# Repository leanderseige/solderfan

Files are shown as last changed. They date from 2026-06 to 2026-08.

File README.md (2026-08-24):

# SolderFan

SolderFan is a modular fume extractor project. It features

- multiple serial 120mm fans (PC case fan standard)
- 100mmm hose adapters
- filter modules for activated carbon filters and for particle filters
- microcontroller based speed adjustment (pwm)
- remote control via bluetooth (from your smartphone or computer)
- tachometer support

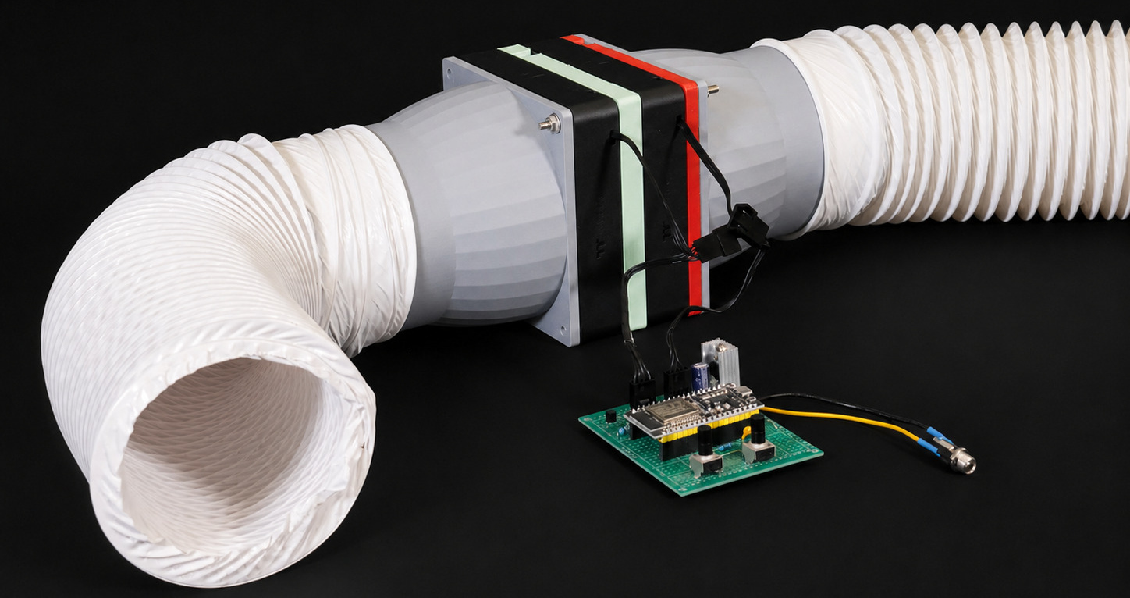
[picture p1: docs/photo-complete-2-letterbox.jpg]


**Disclaimer: This fume extraction system was not professionally designed, engineered, or evaluated. It is an amateur attempt to come up with a practical solution.**

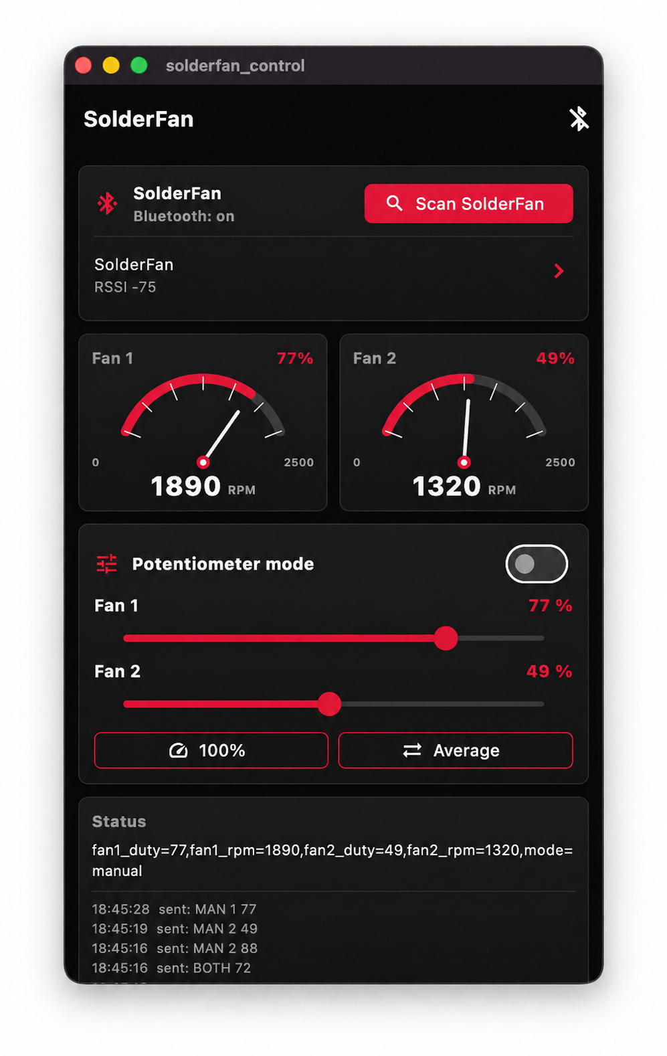
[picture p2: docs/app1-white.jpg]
  

The two-channel ESP32 controller drives two fans with 25 kHz PWM, reads their
tachometer signals, supports an automatic mode through two potentiometers, and
can be controlled over BLE from a Flutter app.

This repository includes STL models for mechanically connecting 120 mm
fans to DN100 hoses.

### Project Layout

```text
.
|-- app/       Flutter app for BLE control
|-- docs/      Schematic and photos
|-- esp32/     PlatformIO project for the ESP32 firmware
`-- stl/       3D models for filter holders, spacers and DN100 hose adapters
```

### Hardware

The firmware is designed for an ESP32 DevKit and two 4-pin PC fans. The fan PWM
outputs are driven through BC547 open-collector stages. Because of that, the PWM
signal is inverted in firmware.

| Function | ESP32 GPIO | Notes |
| --- | ---: | --- |
| Fan 1 tachometer | GPIO19 | Input with internal pull-up |
| Fan 2 tachometer | GPIO18 | Input with internal pull-up |
| Fan 1 PWM | GPIO23 | Through BC547 open-collector stage |
| Fan 2 PWM | GPIO22 | Through BC547 open-collector stage |
| Fan 1 potentiometer | GPIO32 | ADC1_CH4 |
| Fan 2 potentiometer | GPIO33 | ADC1_CH5 |
| 3V3 | - | Potentiometers and tachometer pull-ups |
| GND | - | Common ground for ESP32, fan supply, and signals |

Important: 4-pin PC fans usually require a 12 V supply. The ESP32 3V3 rail is
only intended for signal levels, potentiometers, and pull-ups. The fan supply
ground must be connected to ESP32 GND. The firmware enables the ESP32 internal
pull-ups for the tachometer inputs; if high-RPM readings are still unstable, use
stronger external pull-ups such as 4.7 kOhm to 10 kOhm to 3V3.

### Schematic

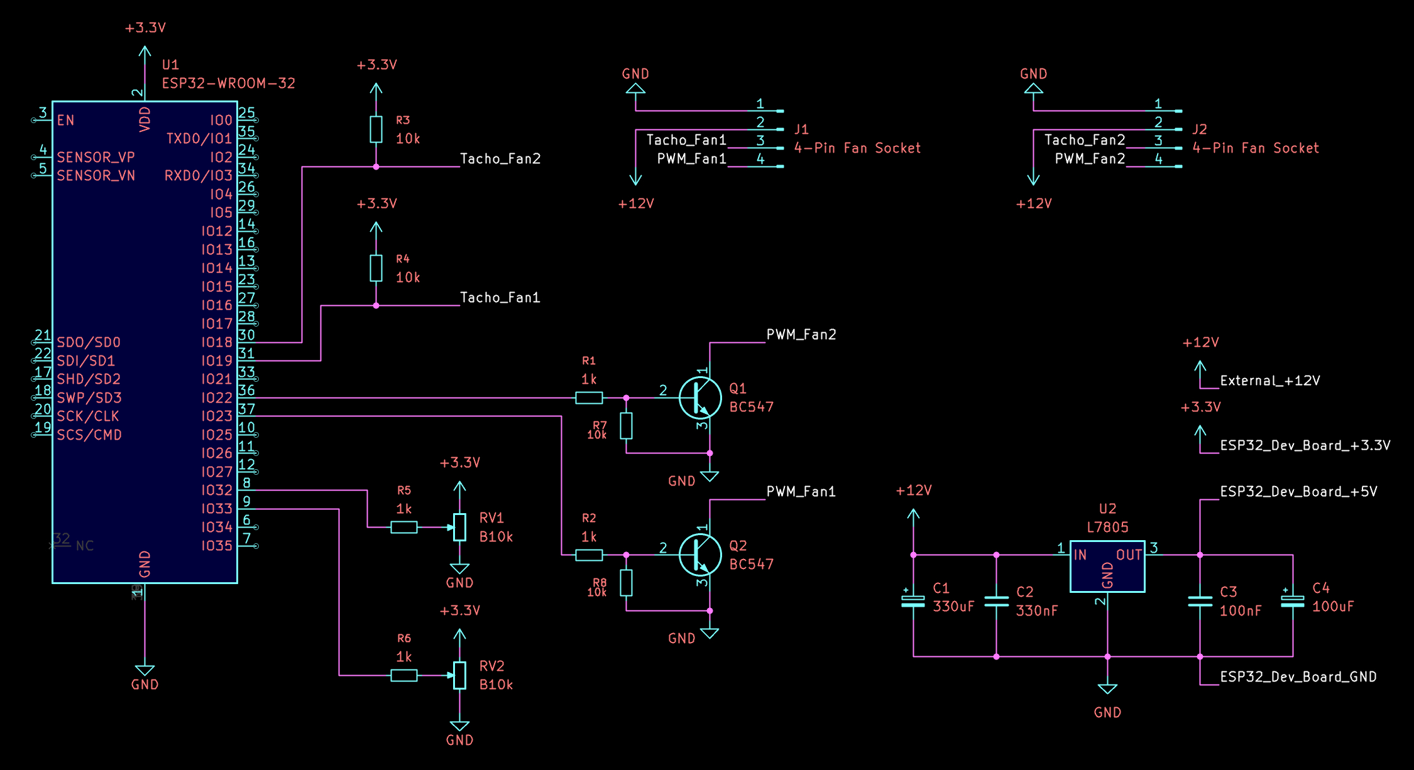
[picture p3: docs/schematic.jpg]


### Firmware

The firmware lives in `esp32/` and is built with PlatformIO.

```bash
cd esp32
pio run
```

Upload:

```bash
cd esp32
pio run -t upload
```

On macOS, you can also use the included script. It uses the first detected port
matching `/dev/cu.usbserial-*`.

```bash
cd esp32
./upload.sh
```

Serial monitor:

```bash
cd esp32
pio device monitor -b 115200
```

### Firmware Behavior

- PWM frequency: 25 kHz
- PWM resolution: 8 bit
- Minimum automatic-mode duty: 20 %
- Tachometer calculation: ESP32 PCNT hardware counter, 2 pulses per revolution
- Automatic mode: Fan 1 follows the potentiometer on GPIO32; Fan 2 follows the
  potentiometer on GPIO33
- Startup behavior: both fans briefly run at 100 %, then fall back to 40 %
- Status output: once per second over Serial and BLE Notify

### BLE Protocol

The ESP32 advertises as:

```text
SolderFan
```

Service UUID:

```text
6e400001-b5a3-f393-e0a9-e50e24dcca9e
```

Write characteristic for commands:

```text
6e400002-b5a3-f393-e0a9-e50e24dcca9e
```

Read/Notify characteristic for status:

```text
6e400003-b5a3-f393-e0a9-e50e24dcca9e
```

Supported text commands:

| Command | Effect |
| --- | --- |
| `AUTO` | Enable automatic mode; the potentiometers control the fans |
| `STATUS` | Send the current status through Notify |
| `BOTH 80` | Manual mode, set both fans to 80 % |
| `MAN 1 70` | Manual mode, set Fan 1 to 70 % |
| `MAN 2 55` | Manual mode, set Fan 2 to 55 % |

Status format:

```text
fan1_duty=40,fan1_rpm=1230,fan2_duty=42,fan2_rpm=1260,mode=auto
```

For quick BLE testing, use a tool such as nRF Connect: scan for the `SolderFan`
device, connect to the service, and write commands as text to the write
characteristic.

## Flutter App



So far I used the app on my laptop only. However it should be possible to run it on phones as well.

The app lives in `app/` and uses `flutter_blue_plus` and `permission_handler`.

```bash
cd app
flutter pub get
flutter run
```

The app scans for the SolderFan BLE service, connects to the ESP32, subscribes
to status notifications, and provides:

- Automatic-mode switch
- Manual sliders for Fan 1 and Fan 2
- Buttons to set both fans to 100 % or to their shared average
- Status display and a small connection/command log

### Android

The required BLE permissions are documented in
`app/android/AndroidManifest-permissions-snippet.xml`. Add them to
`app/android/app/src/main/AndroidManifest.xml` directly below the `<manifest>`
element.

### iOS

The required Bluetooth usage strings are documented in
`app/ios/Info.plist-snippet.xml`. Add them to `ios/Runner/Info.plist` inside the
main `<dict>`. BLE is only practical on real iOS hardware, not in the simulator.

### macOS

For macOS, Bluetooth permissions must be enabled in the Runner entitlements. The
file `app/macos/Runner/DebugProfile.entitlements` is the relevant starting point
in this project.

## STL Models

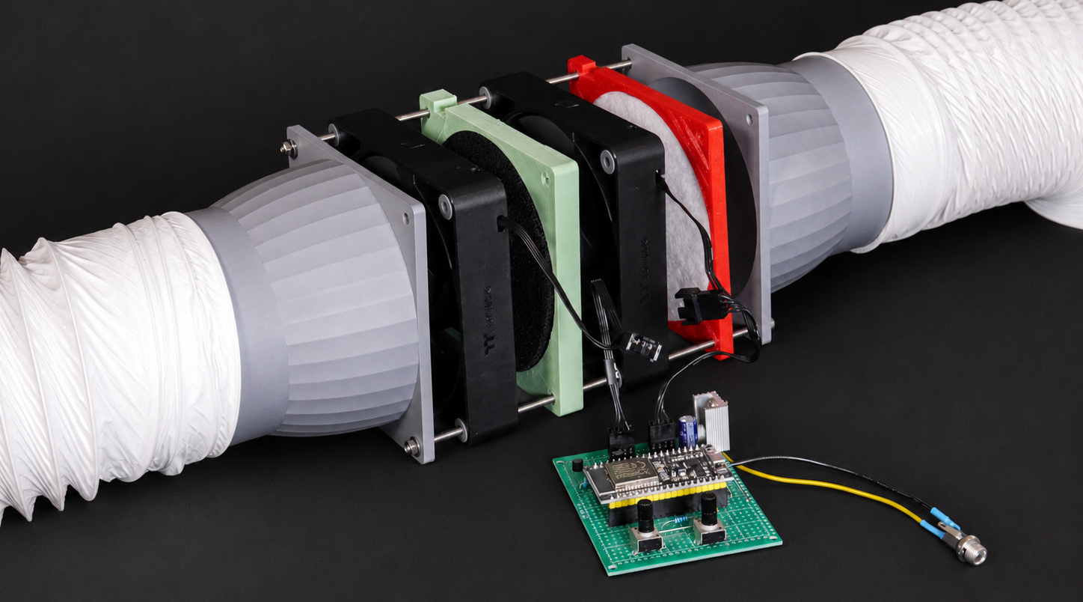
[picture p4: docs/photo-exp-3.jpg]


(Exploded View)

The `stl/` folder contains 3d-models for filter holders, DN100 adapters and spacers.

The models are intended as adapter or spacer parts for combining a 120 mm fan
with DN100 ducting. 

Practical printing notes:

- Check the model dimensions in the slicer before printing.
- Compare the fan mounting hole pattern and DN100 connection against the real
  parts.
- For ABS, ASA, or PETG, use enough wall thickness and consider the temperature
  of the operating environment.

## Filters

The project currently offers two types of filter holders: one for thin particle filter fabric (red) and one for activated carbon filters (green).

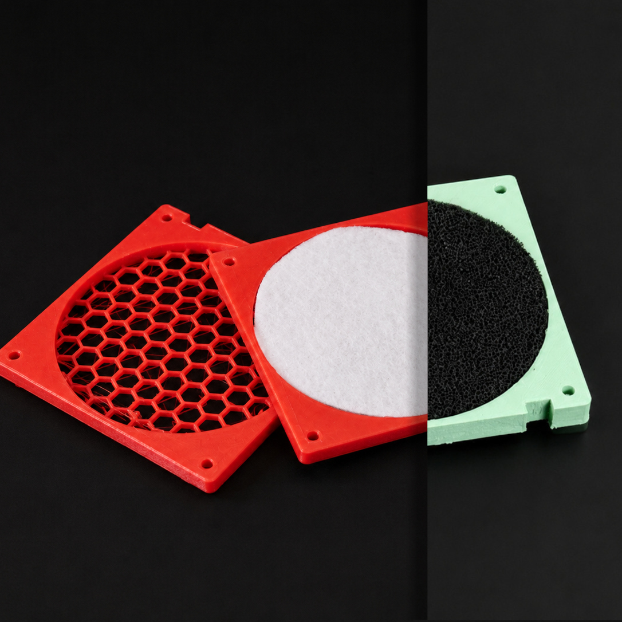
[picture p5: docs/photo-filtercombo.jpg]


## Development Notes

- Generated PlatformIO and Flutter artifacts are ignored through the root
  `.gitignore`.
- The root README is the central project documentation; there is intentionally
  no separate README in the app folder.
- Firmware and app share the BLE protocol. If UUIDs or commands change,
  `esp32/src/main.cpp` and `app/lib/main.dart` must be updated together.

## External Links

- Particle Filter: https://link.amazon/B0b2hkyDI
- Activated Carbon Filter: https://link.amazon/B08j2p6j4
- 120mm Fans (a pair, two): https://link.amazon/B0bdGr0G0
- ESP32 Development Board: https://link.amazon/B0gnhxHe7
- Threaded Rods (M4, 100mm): https://www.amazon.de/dp/B0F1T4DMW3/?tag=seigedigita03-21
- Threaded Rods (M4, 200mm): https://link.amazon/B0fxoyF9D
- 100mm Hose: https://www.ebay.de/itm/384384792852

## Next Ideas

- Presets (Stop / Min / Max / User) incl. Quick Buttons
- Support for local displays / touchscreens
- Support for >2 fans
- Proximity sensor (automatically speed up/down)
- IR sensor (automatically speed up/down)

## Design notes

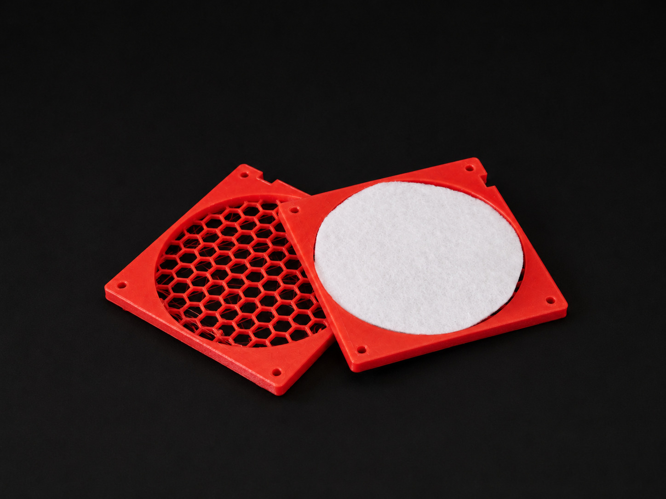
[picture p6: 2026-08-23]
docs/photo-smallfilter-1.jpg

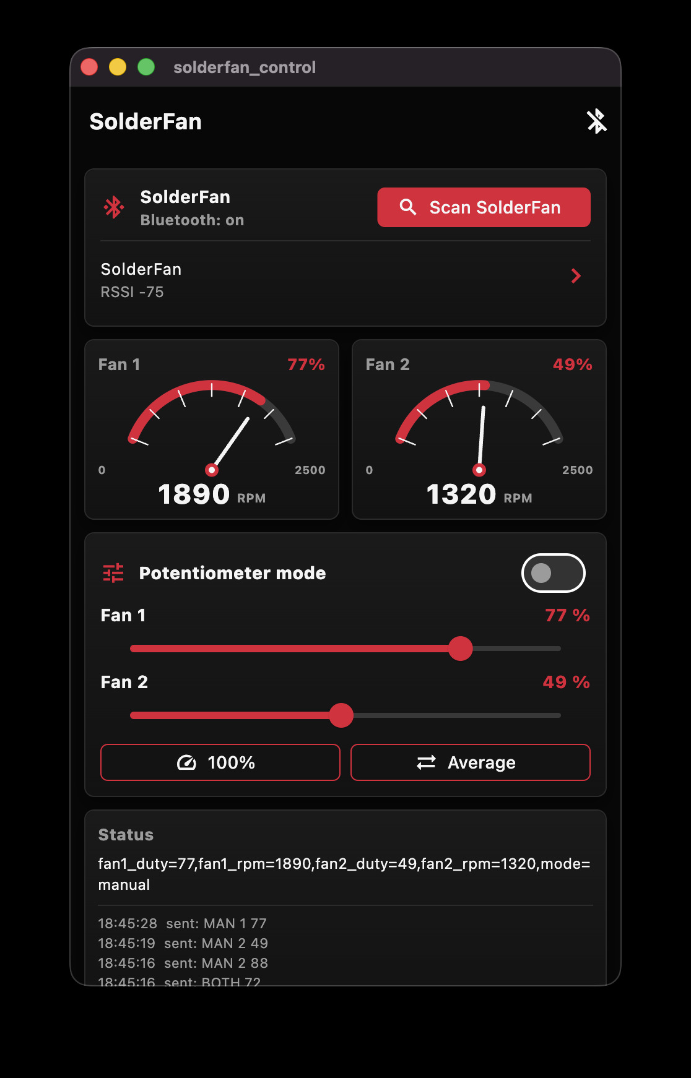
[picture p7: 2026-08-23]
docs/app1.jpg

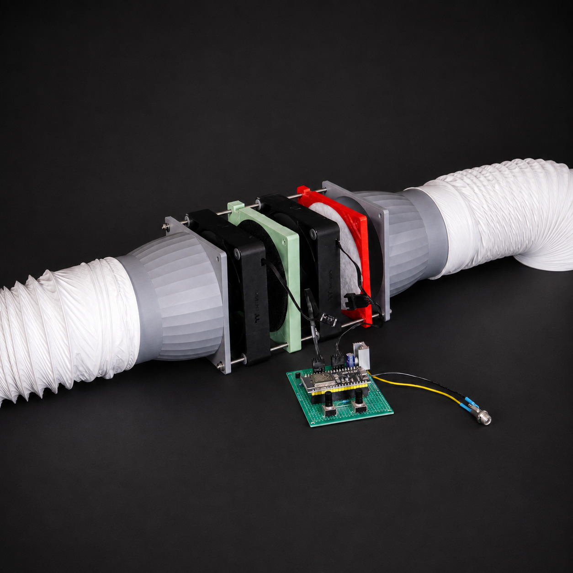
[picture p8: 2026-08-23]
docs/photo-exp-2.jpg

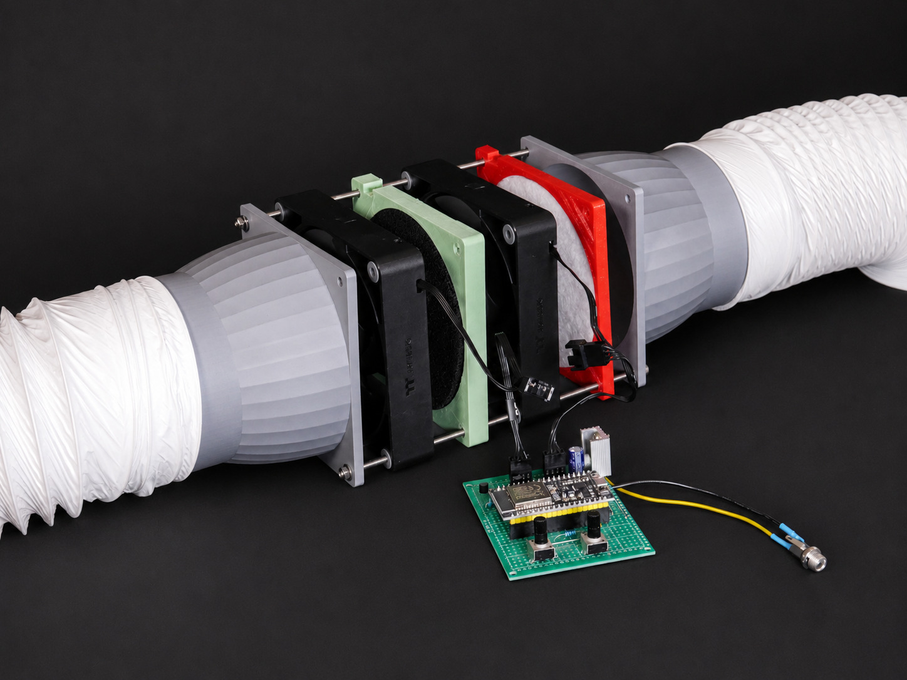
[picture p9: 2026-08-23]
docs/photo-exp-1.jpg

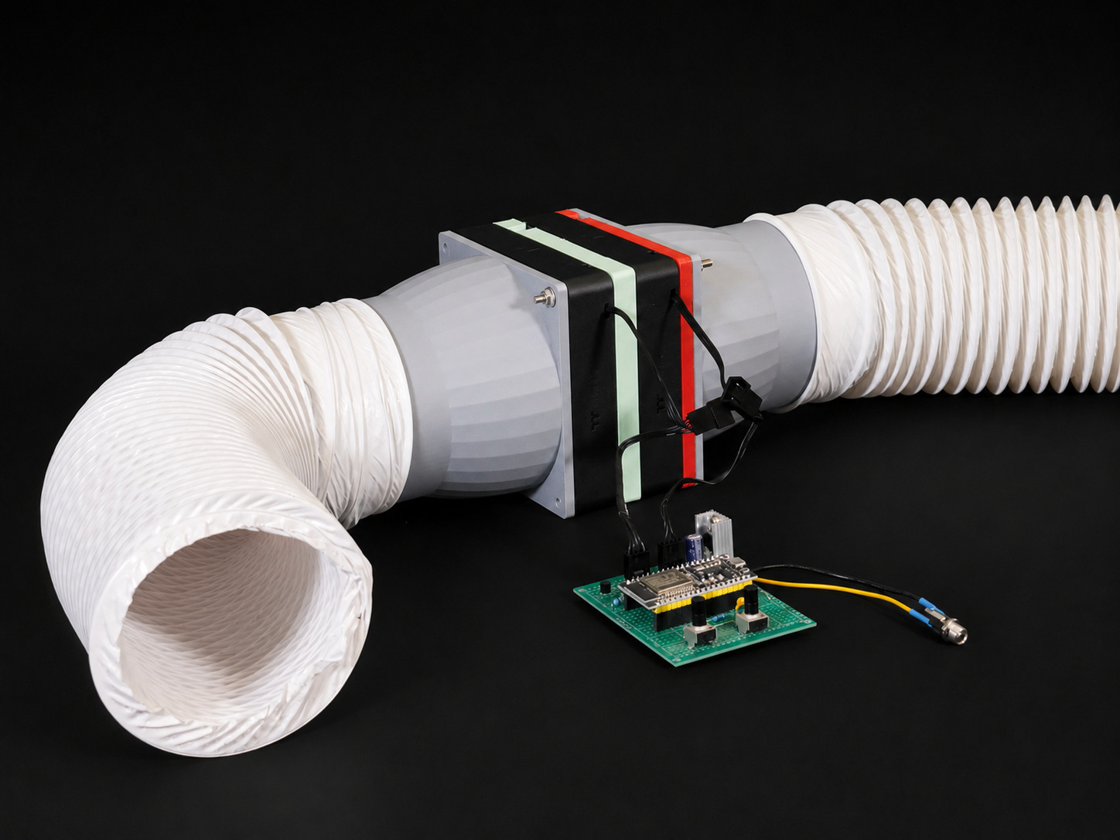
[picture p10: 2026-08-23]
docs/photo-complete-1.jpg

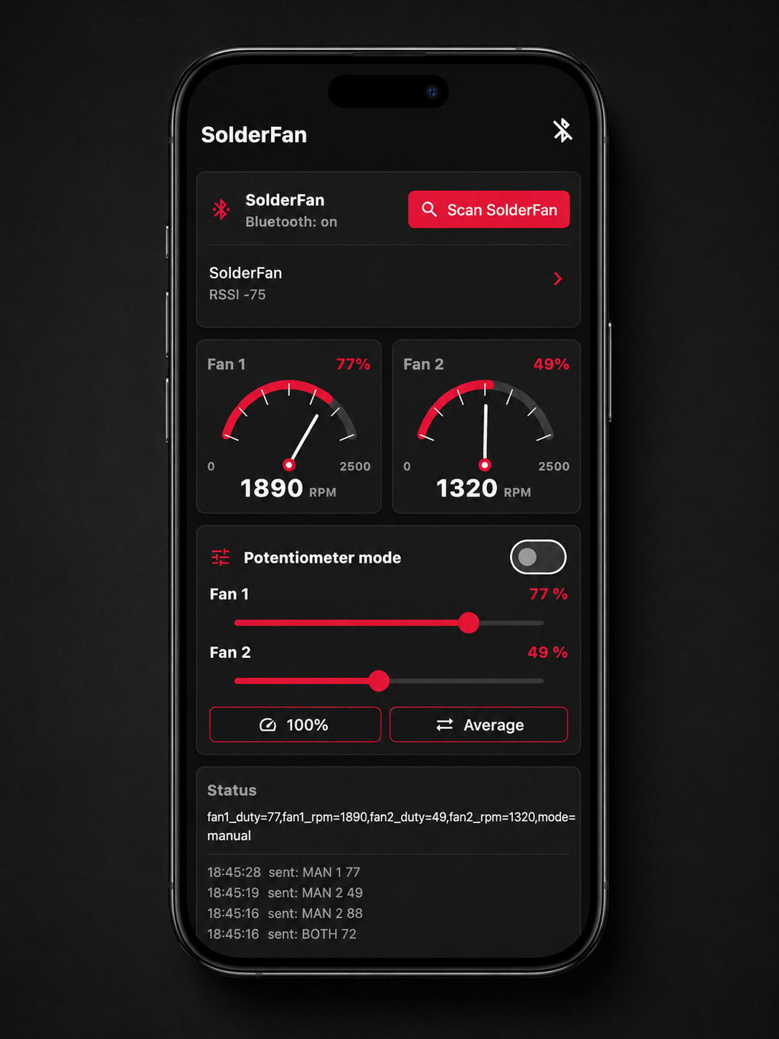
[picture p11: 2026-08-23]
docs/AI-smartphone.jpg

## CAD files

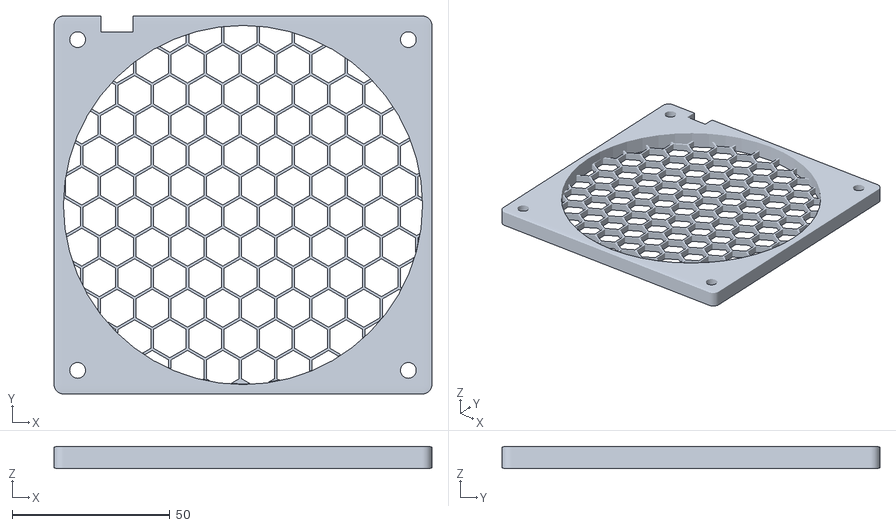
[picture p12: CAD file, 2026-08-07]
stl/filter_4mm.stl
120.0 x 120.0 x 7.00

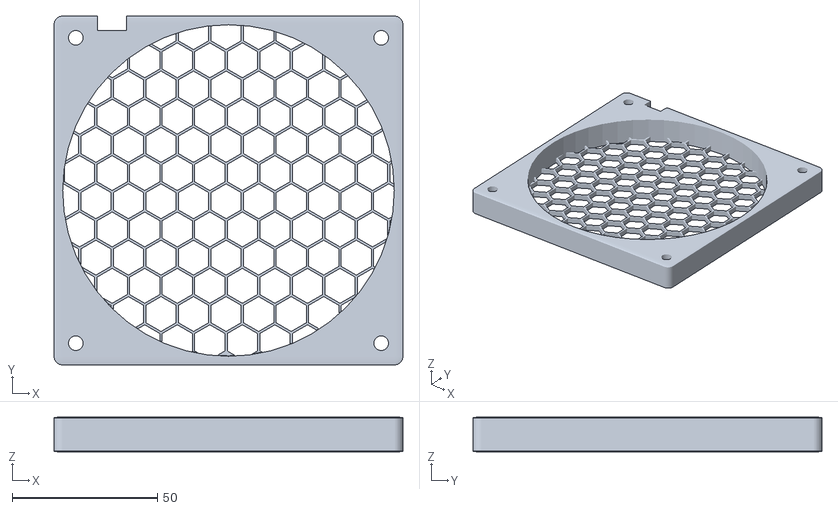
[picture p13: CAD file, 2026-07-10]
stl/filter_10mm.stl
120.0 x 120.0 x 12.0

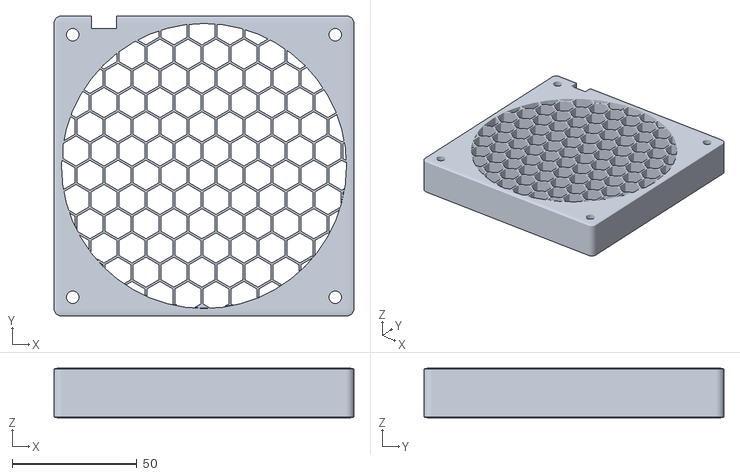
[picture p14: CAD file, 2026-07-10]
stl/hexagons.stl
120.0 x 120.0 x 20.0

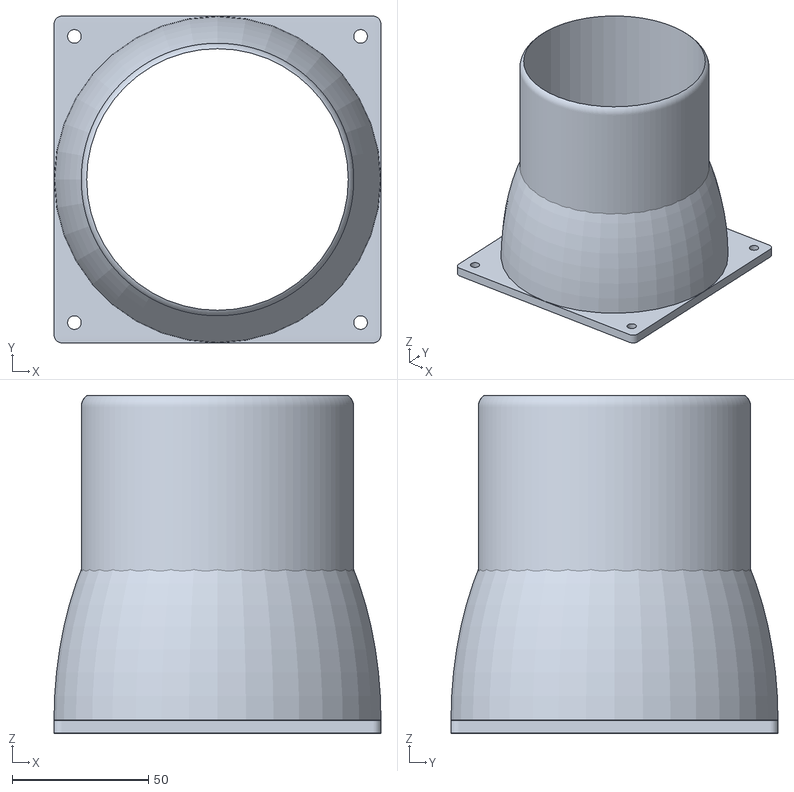
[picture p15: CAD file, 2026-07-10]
stl/DN100_adapter.stl
120.0 x 120.0 x 124.1

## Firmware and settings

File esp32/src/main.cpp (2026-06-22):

#include <Arduino.h>
#include <driver/pcnt.h>
#include <NimBLEDevice.h>

// -------------------- Pins --------------------

constexpr int FAN1_PWM_PIN  = 23;
constexpr int FAN2_PWM_PIN  = 22;

constexpr int FAN1_TACH_PIN = 19;
constexpr int FAN2_TACH_PIN = 18;

constexpr int FAN1_POT_PIN  = 32; // ADC1_CH4
constexpr int FAN2_POT_PIN  = 33; // ADC1_CH5

// -------------------- Fan/PWM settings --------------------

// 4-Pin-PC-Lüfter: typischer PWM-Wert ca. 25 kHz
constexpr uint32_t PWM_FREQ_HZ = 25000;
constexpr uint8_t  PWM_RES_BITS = 8;   // 0..255

// Arduino-ESP32 2.x nutzt LEDC-Kanäle, 3.x arbeitet direkt mit Pins.
constexpr uint8_t FAN1_PWM_CHANNEL = 0;
constexpr uint8_t FAN2_PWM_CHANNEL = 1;

constexpr uint8_t DUTY_MIN_PERCENT = 20;   // unterhalb laufen manche Lüfter unsicher
constexpr uint8_t DUTY_MAX_PERCENT = 100;

// Achtung: mit BJT/Open-Collector ist das Signal invertiert.
// ESP32 HIGH -> BJT leitet -> PWM-Pin des Lüfters LOW.
// Daher invertieren wir die Duty-Ausgabe.
constexpr bool PWM_INVERTED_BY_BJT = true;

// Tacho: PC-Lüfter meist 2 Pulse pro Umdrehung
constexpr uint8_t TACH_PULSES_PER_REV = 2;
constexpr pcnt_unit_t FAN1_TACH_PCNT_UNIT = PCNT_UNIT_0;
constexpr pcnt_unit_t FAN2_TACH_PCNT_UNIT = PCNT_UNIT_1;
constexpr uint16_t TACH_PCNT_FILTER_CYCLES = 1000; // 12.5 us bei 80 MHz APB

// -------------------- State --------------------

uint16_t fan1Rpm = 0;
uint16_t fan2Rpm = 0;

uint8_t fan1DutyPercent = 0;
uint8_t fan2DutyPercent = 0;

bool autoMode = true;

// Für getrennte Regelung kannst du später z.B. fan2 etwas schneller laufen lassen:
int8_t fan1OffsetPercent = 0;
int8_t fan2OffsetPercent = 0;

// BLE
constexpr const char* BLE_DEVICE_NAME = "SolderFan";
NimBLECharacteristic* statusCharacteristic = nullptr;

// -------------------- Helpers --------------------

uint8_t clampPercent(int value) {
  if (value < 0) return 0;
  if (value > 100) return 100;
  return static_cast<uint8_t>(value);
}

uint8_t percentToDutyRaw(uint8_t percent) {
  const uint16_t maxDuty = (1 << PWM_RES_BITS) - 1; // 255 bei 8 Bit
  uint16_t duty = (percent * maxDuty) / 100;

  if (PWM_INVERTED_BY_BJT) {
    duty = maxDuty - duty;
  }

  return static_cast<uint8_t>(duty);
}

void setupFanPwm(uint8_t pin, uint8_t channel) {
#if defined(ESP_ARDUINO_VERSION_MAJOR) && ESP_ARDUINO_VERSION_MAJOR >= 3
  (void)channel;
  ledcAttach(pin, PWM_FREQ_HZ, PWM_RES_BITS);
#else
  ledcSetup(channel, PWM_FREQ_HZ, PWM_RES_BITS);
  ledcAttachPin(pin, channel);
#endif
}

void writeFanPwmRaw(uint8_t pin, uint8_t channel, uint8_t duty) {
#if defined(ESP_ARDUINO_VERSION_MAJOR) && ESP_ARDUINO_VERSION_MAJOR >= 3
  (void)channel;
  ledcWrite(pin, duty);
#else
  (void)pin;
  ledcWrite(channel, duty);
#endif
}

void setFanDutyPercent(uint8_t fan, uint8_t percent) {
  percent = clampPercent(percent);

  uint8_t raw = percentToDutyRaw(percent);

  if (fan == 1) {
    fan1DutyPercent = percent;
    writeFanPwmRaw(FAN1_PWM_PIN, FAN1_PWM_CHANNEL, raw);
  } else {
    fan2DutyPercent = percent;
    writeFanPwmRaw(FAN2_PWM_PIN, FAN2_PWM_CHANNEL, raw);
  }
}

uint8_t readPotPercentSmoothed(uint8_t fan, int potPin) {
  static uint16_t fan1Smooth = 0;
  static uint16_t fan2Smooth = 0;
  uint16_t& smooth = (fan == 1) ? fan1Smooth : fan2Smooth;

  uint16_t raw = analogRead(potPin); // 0..4095 typ.
  smooth = (smooth * 7 + raw) / 8;

  return map(smooth, 0, 4095, DUTY_MIN_PERCENT, DUTY_MAX_PERCENT);
}

void logPcntError(const char* action, esp_err_t result) {
  if (result == ESP_OK) return;

  Serial.print("PCNT ");
  Serial.print(action);
  Serial.print(" failed: ");
  Serial.println(esp_err_to_name(result));
}

void setupTachCounter(int pin, pcnt_unit_t unit) {
  pinMode(pin, INPUT_PULLUP);

  pcnt_config_t config = {};
  config.pulse_gpio_num = pin;
  config.ctrl_gpio_num = PCNT_PIN_NOT_USED;
  config.lctrl_mode = PCNT_MODE_KEEP;
  config.hctrl_mode = PCNT_MODE_KEEP;
  config.pos_mode = PCNT_COUNT_DIS;
  config.neg_mode = PCNT_COUNT_INC;
  config.counter_h_lim = 32767;
  config.counter_l_lim = 0;
  config.unit = unit;
  config.channel = PCNT_CHANNEL_0;

  logPcntError("unit_config", pcnt_unit_config(&config));
  logPcntError("set_filter", pcnt_set_filter_value(unit, TACH_PCNT_FILTER_CYCLES));
  logPcntError("filter_enable", pcnt_filter_enable(unit));
  logPcntError("pause", pcnt_counter_pause(unit));
  logPcntError("clear", pcnt_counter_clear(unit));
  logPcntError("resume", pcnt_counter_resume(unit));
}

uint32_t readAndClearTachCounter(pcnt_unit_t unit) {
  int16_t count = 0;

  pcnt_counter_pause(unit);
  pcnt_get_counter_value(unit, &count);
  pcnt_counter_clear(unit);
  pcnt_counter_resume(unit);

  return count > 0 ? static_cast<uint32_t>(count) : 0;
}

uint16_t pulsesToRpm(uint32_t pulses, uint32_t elapsedMs) {
  if (elapsedMs == 0) return 0;

  uint32_t rpm = (static_cast<uint64_t>(pulses) * 60000ULL) / (TACH_PULSES_PER_REV * elapsedMs);
  if (rpm > UINT16_MAX) return UINT16_MAX;
  return static_cast<uint16_t>(rpm);
}

void updateRpmEverySecond() {
  static uint32_t lastMs = 0;

  uint32_t now = millis();
  uint32_t elapsedMs = now - lastMs;
  if (elapsedMs < 1000) return;

  uint32_t p1 = readAndClearTachCounter(FAN1_TACH_PCNT_UNIT);
  uint32_t p2 = readAndClearTachCounter(FAN2_TACH_PCNT_UNIT);

  fan1Rpm = pulsesToRpm(p1, elapsedMs);
  fan2Rpm = pulsesToRpm(p2, elapsedMs);

  lastMs = now;
}

String makeStatusLine() {
  String s;
  s += "fan1_duty=" + String(fan1DutyPercent);
  s += ",fan1_rpm=" + String(fan1Rpm);
  s += ",fan2_duty=" + String(fan2DutyPercent);
  s += ",fan2_rpm=" + String(fan2Rpm);
  s += ",mode=" + String(autoMode ? "auto" : "manual");
  return s;
}

void notifyStatusEverySecond() {
  static uint32_t lastMs = 0;

  uint32_t now = millis();
  if (now - lastMs < 1000) return;

  String status = makeStatusLine();
  Serial.println(status);

  if (statusCharacteristic) {
    statusCharacteristic->setValue(status.c_str());
    statusCharacteristic->notify();
  }

  lastMs = now;
}

// -------------------- BLE command handling --------------------

class CommandCallbacks : public NimBLECharacteristicCallbacks {
  void onWrite(NimBLECharacteristic* characteristic, NimBLEConnInfo& connInfo) override {
    std::string value = characteristic->getValue();
    String cmd = String(value.c_str());
    cmd.trim();
    cmd.toUpperCase();

    Serial.print("BLE cmd: ");
    Serial.println(cmd);

    if (cmd == "AUTO") {
      autoMode = true;
      return;
    }

    if (cmd == "STATUS") {
      if (statusCharacteristic) {
        String status = makeStatusLine();
        statusCharacteristic->setValue(status.c_str());
        statusCharacteristic->notify();
      }
      return;
    }

    if (cmd.startsWith("BOTH ")) {
      autoMode = false;
      int percent = cmd.substring(5).toInt();
      setFanDutyPercent(1, clampPercent(percent));
      setFanDutyPercent(2, clampPercent(percent));
      return;
    }

    if (cmd.startsWith("MAN ")) {
      autoMode = false;

      // Format: MAN 1 70
      int firstSpace = cmd.indexOf(' ');
      int secondSpace = cmd.indexOf(' ', firstSpace + 1);
      if (secondSpace < 0) return;

      int fan = cmd.substring(firstSpace + 1, secondSpace).toInt();
      int percent = cmd.substring(secondSpace + 1).toInt();

      if (fan == 1 || fan == 2) {
        setFanDutyPercent(fan, clampPercent(percent));
      }
      return;
    }
  }
};

class ServerCallbacks : public NimBLEServerCallbacks {
  void onConnect(NimBLEServer* server, NimBLEConnInfo& connInfo) override {
    (void)server;
    Serial.print("BLE client connected: ");
    Serial.println(connInfo.getAddress().toString().c_str());
  }

  void onDisconnect(NimBLEServer* server, NimBLEConnInfo& connInfo, int reason) override {
    (void)server;
    Serial.print("BLE client disconnected: ");
    Serial.print(connInfo.getAddress().toString().c_str());
    Serial.print(", reason=");
    Serial.println(reason);
    Serial.println("BLE advertising will restart.");
  }
};

// -------------------- BLE setup --------------------

void setupBle() {
  Serial.println("BLE init...");
  NimBLEDevice::init(BLE_DEVICE_NAME);

  NimBLEServer* server = NimBLEDevice::createServer();
  server->setCallbacks(new ServerCallbacks());
  server->advertiseOnDisconnect(true);

  NimBLEService* service = server->createService("6e400001-b5a3-f393-e0a9-e50e24dcca9e");

  // Write-Characteristic: Handy/App -> ESP32
  NimBLECharacteristic* commandCharacteristic = service->createCharacteristic(
    "6e400002-b5a3-f393-e0a9-e50e24dcca9e",
    NIMBLE_PROPERTY::WRITE
  );
  commandCharacteristic->setCallbacks(new CommandCallbacks());

  // Notify-Characteristic: ESP32 -> Handy/App
  statusCharacteristic = service->createCharacteristic(
    "6e400003-b5a3-f393-e0a9-e50e24dcca9e",
    NIMBLE_PROPERTY::READ | NIMBLE_PROPERTY::NOTIFY
  );

  statusCharacteristic->setValue("ready");

  NimBLEAdvertising* advertising = NimBLEDevice::getAdvertising();
  advertising->enableScanResponse(true);
  advertising->setName(BLE_DEVICE_NAME);
  advertising->addServiceUUID(service->getUUID());
  bool advertisingStarted = advertising->start();

  Serial.print("BLE advertising ");
  Serial.print(advertisingStarted ? "started" : "failed to start");
  Serial.print(" as ");
  Serial.println(BLE_DEVICE_NAME);
}

// -------------------- Setup / Loop --------------------

void setup() {
  Serial.begin(115200);
  delay(500);

  // Tacho-Flanken werden per ESP32-PCNT-Hardware gezaehlt.
  setupTachCounter(FAN1_TACH_PIN, FAN1_TACH_PCNT_UNIT);
  setupTachCounter(FAN2_TACH_PIN, FAN2_TACH_PCNT_UNIT);

  analogReadResolution(12);
  analogSetPinAttenuation(FAN1_POT_PIN, ADC_11db);
  analogSetPinAttenuation(FAN2_POT_PIN, ADC_11db);

  // PWM initialisieren
  setupFanPwm(FAN1_PWM_PIN, FAN1_PWM_CHANNEL);
  setupFanPwm(FAN2_PWM_PIN, FAN2_PWM_CHANNEL);

  // Anlaufkick
  setFanDutyPercent(1, 100);
  setFanDutyPercent(2, 100);
  delay(1000);

  setFanDutyPercent(1, 40);
  setFanDutyPercent(2, 40);

  setupBle();

  Serial.println("Lüftersteuerung gestartet.");
}

void loop() {
  updateRpmEverySecond();

  if (autoMode) {
    uint8_t fan1 = clampPercent(readPotPercentSmoothed(1, FAN1_POT_PIN) + fan1OffsetPercent);
    uint8_t fan2 = clampPercent(readPotPercentSmoothed(2, FAN2_POT_PIN) + fan2OffsetPercent);

    setFanDutyPercent(1, fan1);
    setFanDutyPercent(2, fan2);
  }

  notifyStatusEverySecond();

  delay(10);
}

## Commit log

2026-06-22 Clarify STL models description in README
    Updated description of STL models for clarity and accuracy.
2026-07-10 better stl models
    [120Fan2DN100-B.stl, 120Fan2DN100.stl, DN100_adapter.stl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]
2026-08-07 4mm filter added
    [filter_4mm.stl]
2026-08-08 schematic added
2026-08-23 schematic fixed
2026-08-23 Update README with STL models description
    Added information about the purpose of STL models.
2026-08-23 Add link for 100mm Hose to README
